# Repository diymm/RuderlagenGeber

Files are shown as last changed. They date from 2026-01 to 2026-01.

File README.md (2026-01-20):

## RuderlagenGeber NMEA 2000
Sensor im Eigenbau mit N2K Schnittstelle.
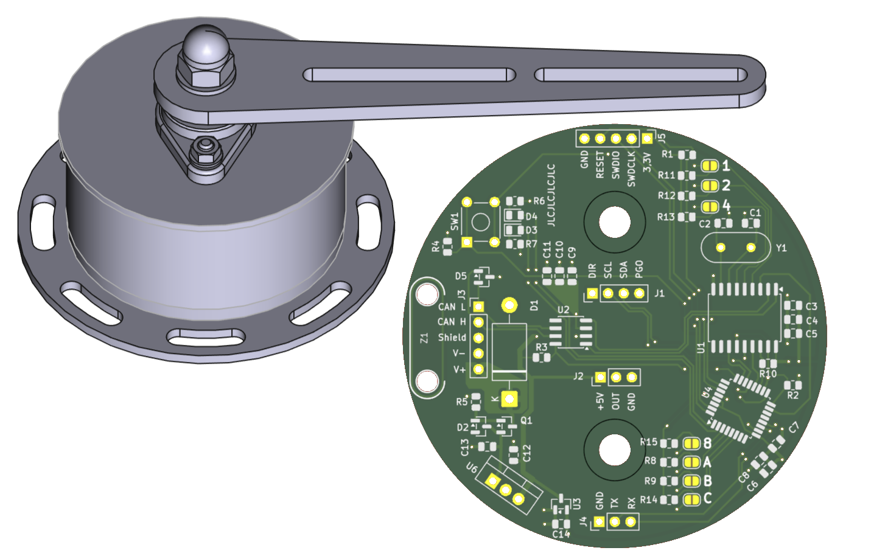
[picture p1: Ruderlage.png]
Ruderlagengeber


### Mechanischer Aufbau
Durch die Verwendung von Aluminium Blechteilen und Normteilen wird 
ein preisgünstigen Aufbau ermöglicht.\
Die Positionserfassung erfolgt magnetisch verschleissfrei und wird über 360°,\
ohne Anschlag erfasst. Eine mechanische Ausrichtung des Gebers ist nicht notwendig.
Über einen Taster wird die 0° Grad Position festgelegt und\
es kann eine Drehrichtungsumkehr eingeschaltet werden.

### Elektronik
Die Schaltung ist gegen Verpolung und Spannungspitzen geschützt\
und besteht im wesentlichen aus drei Komponenten:\
Dem Positionssensor AS5600\
einem CAN BUS Controller MCP2515\
und dem Kontroller SAMD21G17.\
Die Spannungsregelung wird energiesparend über einen Schaltregler geregelt. 
 
### Firmware
Die Firmware ist aktuell noch in der Testphase und wird noch ergänzt.
Im Testmode werden über die RS232 TTL verschiedene Zustände und Messwerte angezeigt,
auch ohne Ausgabe der Werte ist es mit Hilfe der LED möglich den Abstand des Magnetsensors
ausreichend genau einzustellen. 

### Vorstellung des Projekts auf YouTube
Eine Video Unterstützung auf YouTube steht zur weiteren Unterstützung bereit.
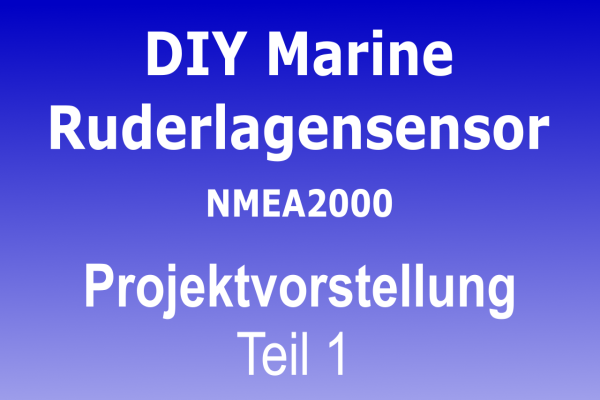
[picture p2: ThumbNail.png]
RuderlageThumbnail (https://www.youtube.com/watch?v=PicgXwzTuoU&t)


### Dokumentation
Durch die Verendung von KiCad für den Schaltplan und FreeCAD für die Zeichnungen ist eine Anpassung
an eigene Vorstellungen möglich.

### Lizenz
Alle Zeichnungen und der Programmcode können frei, nicht kommerziell, verwendet werden.\
creative commons (CC BY-NC 4.0) https://creativecommons.org/licenses/

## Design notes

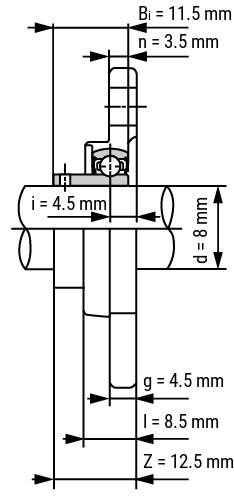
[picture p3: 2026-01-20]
Zeichnungen/silber-serie-miniatur-flanschlager-kfl08-welle-8-mm~3.jpg

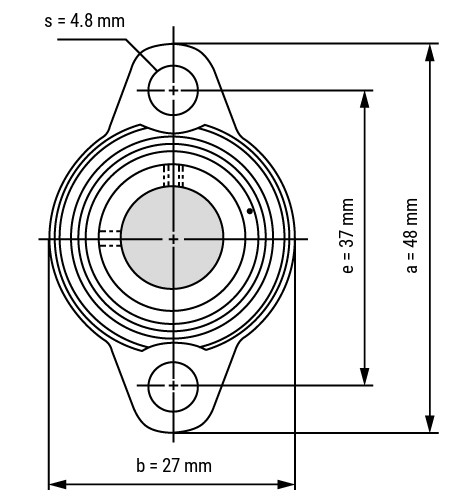
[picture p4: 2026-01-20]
Zeichnungen/silber-serie-miniatur-flanschlager-kfl08-welle-8-mm~2.jpg

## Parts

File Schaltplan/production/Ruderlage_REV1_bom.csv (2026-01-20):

Designator | Footprint | Quantity | Value | LCSC Part #
C1, C2 | 0805 | 2 | 22pF | C123150
C10, C4, C7 | 0805 | 3 | 1uF | C141772
C11, C3, C8 | 0805 | 3 | 100pF | C9900195991
C12, C13, C14, C5, C6, C9 | 0805 | 6 | 10uF | C356840
D1 | D_DO-201AE_P15.24mm_Horizontal | 1 | 1.5KExxA
D2 | SOT-23 | 1 | BZX 84-C4V7 | C143853
D3 | 0805 | 1 | LED gn | C2297
D4 | 0805 | 1 | LED rt | C84256
D5 | SOT-23 | 1 | PESD1CAN
Q1 | SOT-23 | 1 | NX2301P | C551594
R1 | 0805 | 1 | 1k | C9900143942
R10, R11, R14, R15, R2, R8, R9 | 0805 | 7 | 10k | C9900234692
R12, R13, R3, R4, R5 | 0805 | 5 | 10k
R6, R7 | 0805 | 2 | 200 | C2889551
SW1 | SW_TH_Tactile_Omron_B3F-10xx | 1 | SW_Omron_B3FS
U1 | SOIC-18W_7.5x11.6mm_P1.27mm | 1 | MCP2515-xSO
U2 | SOIC-8_3.9x4.9mm_P1.27mm | 1 | TJA1051T
U3 | SOT-23 | 1 | MCP1700x-120xxTT
U4 | TQFP-32_7x7mm_P0.8mm | 1 | ATSAMD21E17A-A | C618766
Z1 | Zugentlastung | 1 | ~

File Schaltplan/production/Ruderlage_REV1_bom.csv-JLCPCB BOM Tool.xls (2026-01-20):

JLCPCB BOM Tool - BOM Matching
BOM name：Ruderlage_REV1_bom-JLCPCB Assembly Order.xlsx |  |  |  | Download Time：2025-11-30 02:08:21 |  |  |  | * Our matching results are updated in real-time, but stock and prices may change. If it's been over 24 hours, please re-match before placing your order.
PCB Assembled Qty：5 |  |  |  | Est. Total Price：33.3095 (Pre-order parts require a quotation for final pricing.)
Your BOM |  |  |  | Matched Parts |  |  |  |  |  |  | Order Information
Designator | Comment | Footprint | JLCPCB Part # | Matches | Part # | Manufacturer | Footprint | Description | Category | Warning | JLCPCB Part # | Product link | Source | Lib Type | MOQ | Availability | My Parts(JLCPCB Parts) | My Parts(Global sourcing & consigned parts) | Rec. Order Qty | Unit Price ($) | Total Price ($)
U1 | MCP2515-xSO | SOIC-18W_7.5x11.6mm_P1.27mm |  | Select by System | MCP2515T-I/SO | Microchip Tech | SOIC-18W_7.5x11.6mm_P1.27mm | -40℃~+85℃ 1Mbps 1uA 2.7V~5.5V 5mA CAN Controller SPI SOIC-18-300mil CAN Controllers ROHS | CAN Controllers |  | C153782 | https://jlcpcb.com/partdetail/MicrochipTech-MCP2515T_ISO/C153782 | In-stock | Extended | 1 | 610 | 0 | 0 | 5 | 1.2885 | 6.4425
Q1 | NX2301P | SOT-23 |  | Select by Customer | NX2301P,215 | Nexperia | SOT-23 | -55℃~+150℃ 1 P-Channel 1.1V@250uA 115pF 120mΩ@4.5V 20V 2A 380pF 400mW 6nC@4.5V P-Channel SOT-23 MOSFETs ROHS | MOSFETs |  | C191273 | https://jlcpcb.com/partdetail/Nexperia-NX2301P215/C191273 | In-stock | Extended | 1 | 62 | 0 | 0 | 9 | 0.1847 | 1.6623
D2 | BZX 84-C4V7 | SOT-23 |  | Select by System | BZB784-C4V7,115 | Nexperia | SOT-23 | 1 Pair Common Anode 350mW 3uA@2V 4.4V~5V 4.7V 80Ω SOT-323(SC-70) Zener Diodes ROHS | Zener Diodes |  | C503444 | https://jlcpcb.com/partdetail/Nexperia-BZB784_C4V7115/C503444 | In-stock | Extended | 1 | 1321 | 0 | 0 | 9 | 0.1193 | 1.0737
C11,C3,C8 | 100pF | 0805 |  | Select by System | CC0805JRNPO9BN101 | YAGEO | 0805 | 100pF 50V NP0 ±5% 0805 Multilayer Ceramic Capacitors MLCC - SMD/SMT ROHS | Multilayer Ceramic Capacitors MLCC - SMD/SMT |  | C62768 | https://jlcpcb.com/partdetail/YAGEO-CC0805JRNPO9BN101/C62768 | In-stock | Extended | 1 | 33006 | 0 | 0 | 25 | 0.0053 | 0.1325
R10,R11,R14,R15,R2,R8,R9 | 10k | 0805 |  | Select by System | 0805W8F1002T5E | UNI-ROYAL(Uniroyal Elec) | 0805 | -55℃~+155℃ 10kΩ 125mW 150V Thick Film Resistor ±1% ±100ppm/℃ 0805 Chip Resistor - Surface Mount ROHS | Chip Resistor - Surface Mount |  | C17414 | https://jlcpcb.com/partdetail/18102-0805W8F1002T5E/C17414 | In-stock | Basic | 1 | 12077584 | 0 | 0 | 70 | 0.0018 | 0.126
R12,R13,R3,R4,R5 | 10k | 0805 |  | Unconfirmed | 0805W8F1002T5E | UNI-ROYAL(Uniroyal Elec) | 0805 | -55℃~+155℃ 10kΩ 125mW 150V Thick Film Resistor ±1% ±100ppm/℃ 0805 Chip Resistor - Surface Mount ROHS | Chip Resistor - Surface Mount | 1.The comment (0805W8F1002T5E) of this part does not match the one (10k) provided in your BOM. Please confirm; | C17414 | https://jlcpcb.com/partdetail/18102-0805W8F1002T5E/C17414 | In-stock | Basic | 1 | 12077584 | 0 | 0 | 70 | 0.0018 | 0.126
R1 | 1k | 0805 |  | Select by System | 0805W8F1001T5E | UNI-ROYAL(Uniroyal Elec) | 0805 | -55℃~+155℃ 125mW 150V 1kΩ Thick Film Resistor ±1% ±100ppm/℃ 0805 Chip Resistor - Surface Mount ROHS | Chip Resistor - Surface Mount |  | C17513 | https://jlcpcb.com/partdetail/18201-0805W8F1001T5E/C17513 | In-stock | Basic | 1 | 15084219 | 0 | 0 | 20 | 0.0017 | 0.034
U4 | ATSAMD21E17A-A | TQFP-32_7x7mm_P0.8mm |  | Select by System | ATSAMD21E17A-AU | Microchip Tech | TQFP-32_7x7mm_P0.8mm | 1.62V~3.6V 10bit 128KB 12bit 26 48MHz ARM Cortex-M Series FLASH TQFP-32(7x7) Microcontrollers (MCU/MPU/SOC) ROHS | Microcontrollers (MCU/MPU/SOC) |  | C1337408 | https://jlcpcb.com/partdetail/MicrochipTech-ATSAMD21E17AAU/C1337408 | In-stock | Extended | 1 | 20 | 0 | 0 | 5 | 3.813 | 19.065
C10,C4,C7 | 1uF | 0805 |  | Select by System | CL21B105KOFNNNE | Samsung Electro-Mechanics | 0805 | 16V 1uF X7R ±10% 0805 Multilayer Ceramic Capacitors MLCC - SMD/SMT ROHS | Multilayer Ceramic Capacitors MLCC - SMD/SMT |  | C24123 | https://jlcpcb.com/partdetail/24863-CL21B105KOFNNNE/C24123 | In-stock | Extended | 1 | 331792 | 0 | 0 | 25 | 0.0097 | 0.2425
C12,C13,C14,C5,C6,C9 | 10uF | 0805 |  | Select by System | CL21A106KPFNNNE | Samsung Electro-Mechanics | 0805 | 10V 10uF X5R ±10% 0805 Multilayer Ceramic Capacitors MLCC - SMD/SMT ROHS | Multilayer Ceramic Capacitors MLCC - SMD/SMT |  | C17024 | https://jlcpcb.com/partdetail/17708-CL21A106KPFNNNE/C17024 | In-stock | Extended | 1 | 1625820 | 0 | 0 | 40 | 0.0091 | 0.364
D5 | PESD1CAN | SOT-23 |  | Select by System | PESD1CAN | BORN | SOT-23 | 12pF 24V 26.7V 280W@8/20us 48V 500nA 6A Bidirectional ESD IEC 61000-4-2 SOT-23 ESD and Surge Protection (TVS/ESD) ROHS | ESD and Surge Protection (TVS/ESD) |  | C343993 | https://jlcpcb.com/partdetail/BORN-PESD1CAN/C343993 | In-stock | Extended | 1 | 64359 | 0 | 0 | 9 | 0.075 | 0.675
R6,R7 | 200 | 0805 |  | Select by System | 0805W8F2000T5E | UNI-ROYAL(Uniroyal Elec) | 0805 | -55℃~+155℃ 125mW 150V 200Ω Thick Film Resistor ±1% ±100ppm/℃ 0805 Chip Resistor - Surface Mount ROHS | Chip Resistor - Surface Mount |  | C17540 | https://jlcpcb.com/partdetail/18228-0805W8F2000T5E/C17540 | In-stock | Basic | 1 | 1684208 | 0 | 0 | 20 | 0.0018 | 0.036
C1,C2 | 22pF | 0805 |  | Select by System | CL21C220JBANNNC | Samsung Electro-Mechanics | 0805 | 22pF 50V C0G ±5% 0805 Multilayer Ceramic Capacitors MLCC - SMD/SMT ROHS | Multilayer Ceramic Capacitors MLCC - SMD/SMT |  | C1804 | https://jlcpcb.com/partdetail/2156-CL21C220JBANNNC/C1804 | In-stock | Basic | 1 | 405912 | 0 | 0 | 20 | 0.0091 | 0.182
D4 | LED rt | 0805 |  | Select by System | NCD0805R1 | Foshan NationStar Optoelectronics | 0805 | -30℃~+85℃ 1.6V~2.6V 130° 195mcd 25mA 615nm~630nm 630nm 65mW Discrete Diode Red 0805 LED Indication - Discrete ROHS | LED Indication - Discrete |  | C84256 | https://jlcpcb.com/partdetail/85425-NCD0805R1/C84256 | In-stock | Basic | 1 | 6231906 | 0 | 0 | 20 | 0.0116 | 0.232
D3 | LED gn | 0805 |  | Select by System | KT-0805G | Hubei KENTO Elec | 0805 | -40℃~+85℃ 100mW 120° 2.6V~3.1V 430mcd 513nm~528nm 525nm 5mA Emerald Green 0805 LED Indication - Discrete ROHS | LED Indication - Discrete |  | C2297 | https://jlcpcb.com/partdetail/Hubei_KENTOElec-KT0805G/C2297 | In-stock | Basic | 1 | 2581235 | 0 | 0 | 20 | 0.0108 | 0.216
U2 | TJA1051T | SOIC-8_3.9x4.9mm_P1.27mm |  | Select by System | TJA1051T | Tokmas | SOIC-8_3.9x4.9mm_P1.27mm | -40℃~+150℃ 4.5V~5.5V 5Mbps 70mA CAN FD Transceiver SOP-8 CAN Transceivers ROHS | CAN Transceivers |  | C7432801 | https://jlcpcb.com/partdetail/Tokmas-TJA1051T/C7432801 | In-stock | Extended | 1 | 1532 | 0 | 0 | 5 | 0.54 | 2.7
Z1 | ~ | Zugentlastung |  | No matches |  | No Part Selected
D1 | 1.5KExxA | D_DO-201AE_P15.24mm_Horizontal |  | No matches |  | No Part Selected
SW1 | SW_Omron_B3FS | SW_TH_Tactile_Omron_B3F-10xx |  | No matches |  | No Part Selected
U3 | MCP1700x-120xxTT | SOT-23 |  | No matches |  | No Part Selected

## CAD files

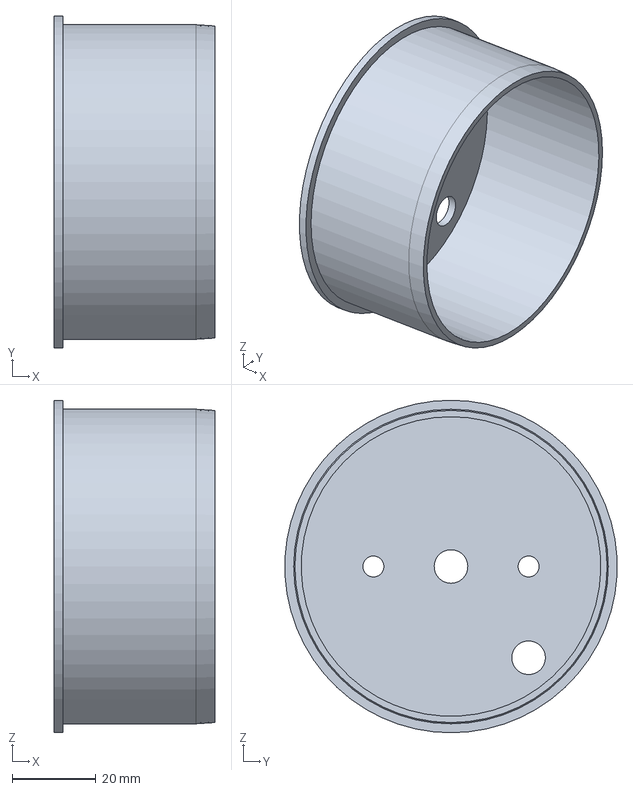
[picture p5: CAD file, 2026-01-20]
Zeichnungen/HtMuffenstopfenDn75.FCStd
38.3 x 79.1 x 79.3 mm

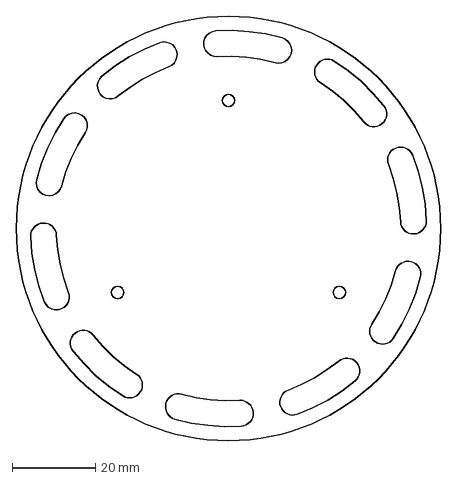
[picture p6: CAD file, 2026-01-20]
Zeichnungen/Ruderlage_Bodenplatte.dxf
102.0 x 102.0 mm

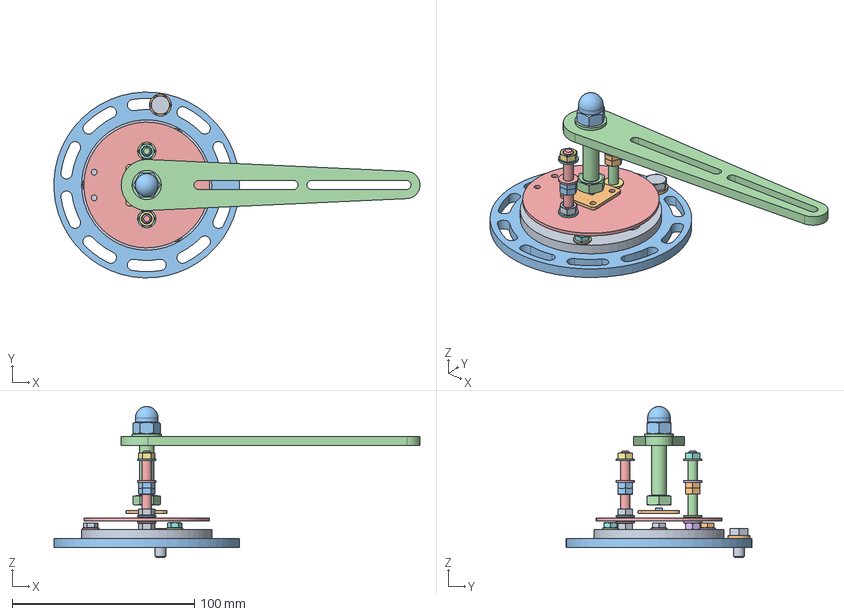
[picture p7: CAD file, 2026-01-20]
Zeichnungen/RuderlageV2.FCStd
200.9 x 102.0 x 82.9 mm
Montageplatte
Platine
Soic8
M5x48-ThreadedRod
M5x48-ThreadedRod001
M5-Nut
M5-Nut007
M5-Nut008
M5-Nut016
M5-Nut009
M5-Nut010
M5-Washer001
M5-Washer003
M5-Washer002
M5-Washer004
M5-Washer005
M6x12-Screw
M6-Washer
M8-Nut
M5-Washer
M5-Washer016
M5-Washer014
M5-Washer015
M5-Nut017
M5-Nut011
M5-Nut012
M8-Washer
M4-Washer
M4-Washer003
M4-Washer004
M4x10-Screw0
M4x10-Screw
M4x10-Screw001
Montageplatte1
Arm001
MotherBoard

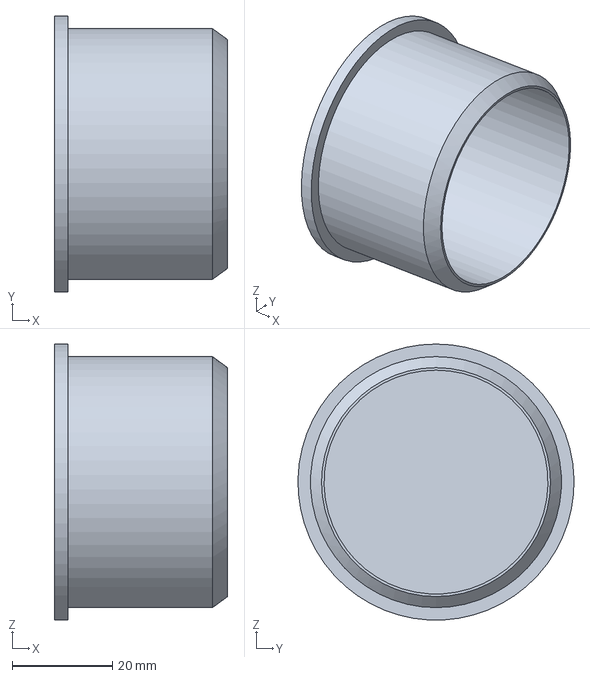
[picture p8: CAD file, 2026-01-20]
Zeichnungen/HtMuffenstopfenDn50.FCStd
34.5 x 55.0 x 55.0 mm

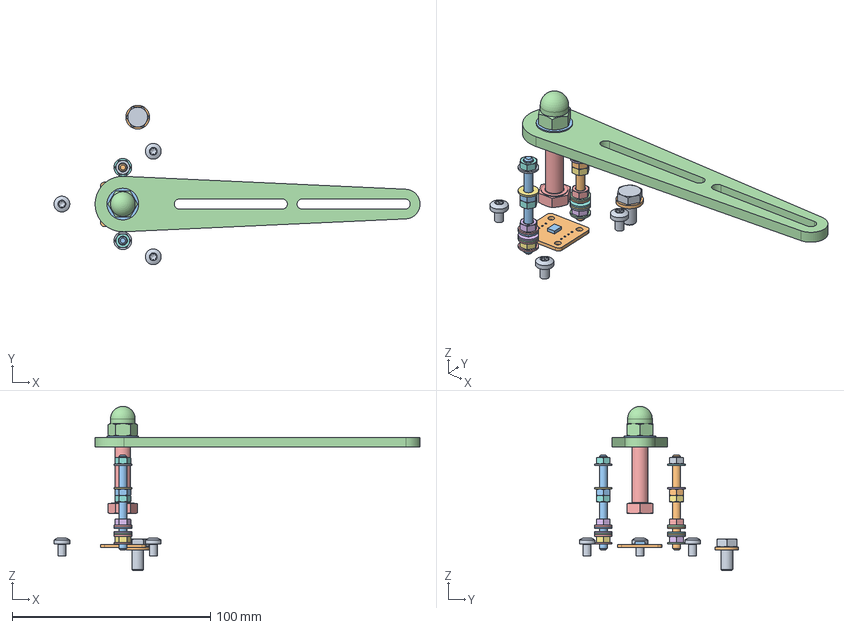
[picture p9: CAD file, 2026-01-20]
Zeichnungen/Ruderlage.FCStd
184.7 x 80.5 x 82.9 mm
Platine
Soic8
Arm001
M4-Nut
M4-Nut016
M4-Nut018
M4-Nut017
M4-Nut022
M4-Nut021
M8-Nut
M4-Nut025
M4-Nut024
M4-Nut028
M4-Nut029
M6x12-Screw
M4x48-ThreadedRod
M4x48-ThreadedRod001
M4-Washer
M4-Washer014
M4-Washer020
M4-Washer019
M4-Washer015
M4-Washer016
M6-Washer
M8-Washer
M4-Washer025
M4-Washer026
M4-Washer027
M4-Washer051
M4-Washer052
M4-Washer053
M4-Washer056
M4-Washer054
M4-Washer057
M4-Washer055

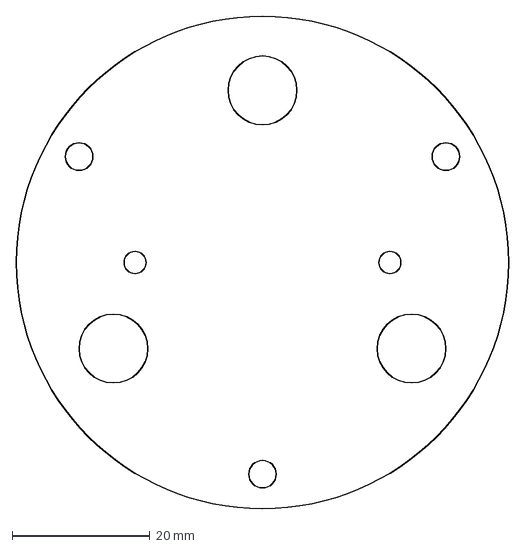
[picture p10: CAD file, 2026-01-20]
Zeichnungen/Ruderlage_Innenplatte.dxf
71.5 x 71.5 mm

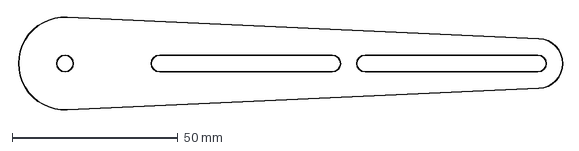
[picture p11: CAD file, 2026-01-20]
Zeichnungen/Ruderlage_Arm.dxf
164.7 x 28.4 mm

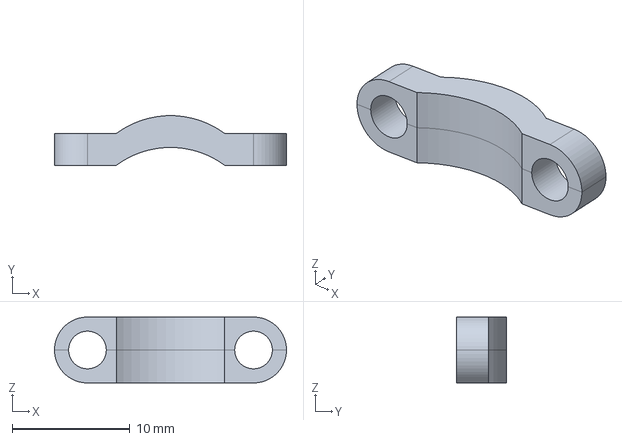
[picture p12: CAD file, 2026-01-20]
Zeichnungen/ZugentlastungKAZU_0442.FCStd
19.7 x 4.21 x 5.60 mm

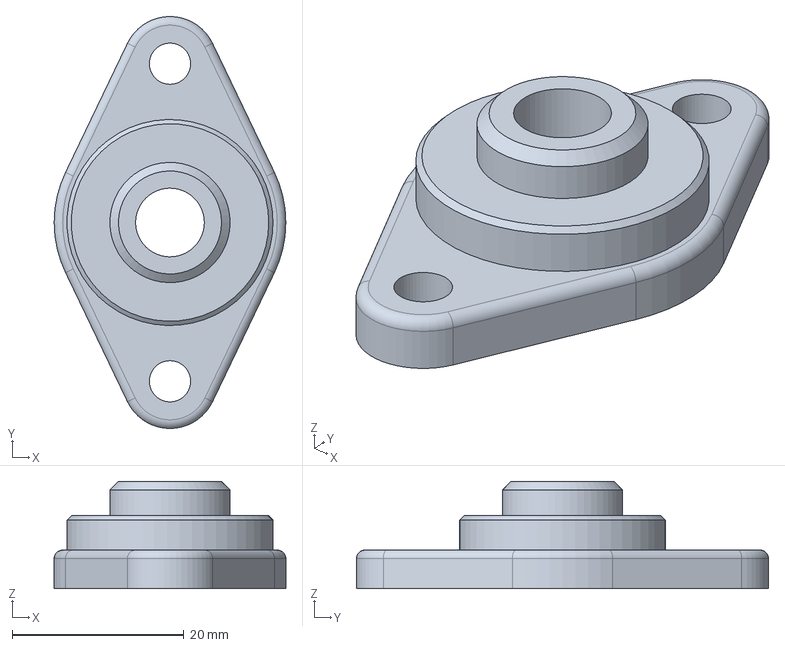
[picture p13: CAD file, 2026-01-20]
Zeichnungen/KFL08.FCStd
27.0 x 48.0 x 12.5 mm

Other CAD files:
Zeichnungen/Assembly.FCStd
Zeichnungen/WinkelTestZeichnung.FCStd

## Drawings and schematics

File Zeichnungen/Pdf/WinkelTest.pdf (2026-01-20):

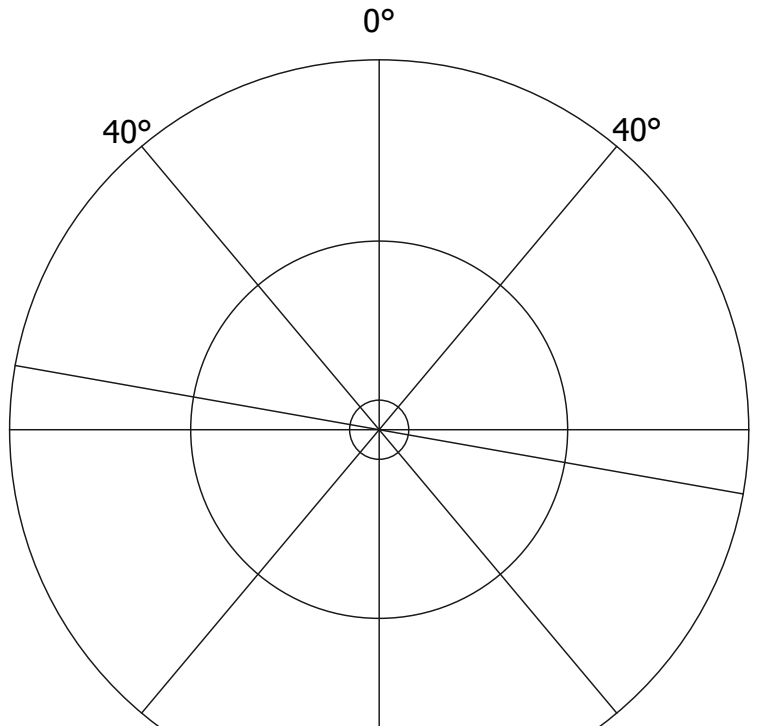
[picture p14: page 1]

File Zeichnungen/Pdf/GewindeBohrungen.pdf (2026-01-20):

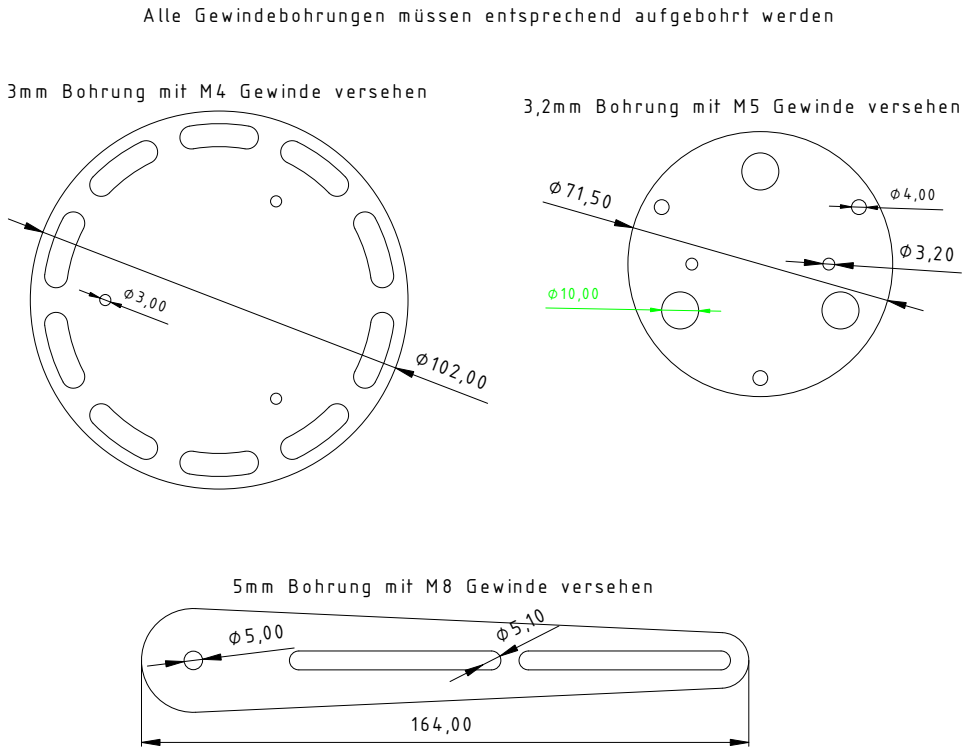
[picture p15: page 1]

A lle G e w indebohrungen m üssen entsprechend aufgebohrt w erden

3m m B ohrung m it M 4 G e w inde versehen

3,2m m B ohrung m it M 5 G e w inde versehen

5m m B ohrung m it M 8 G e w inde versehen

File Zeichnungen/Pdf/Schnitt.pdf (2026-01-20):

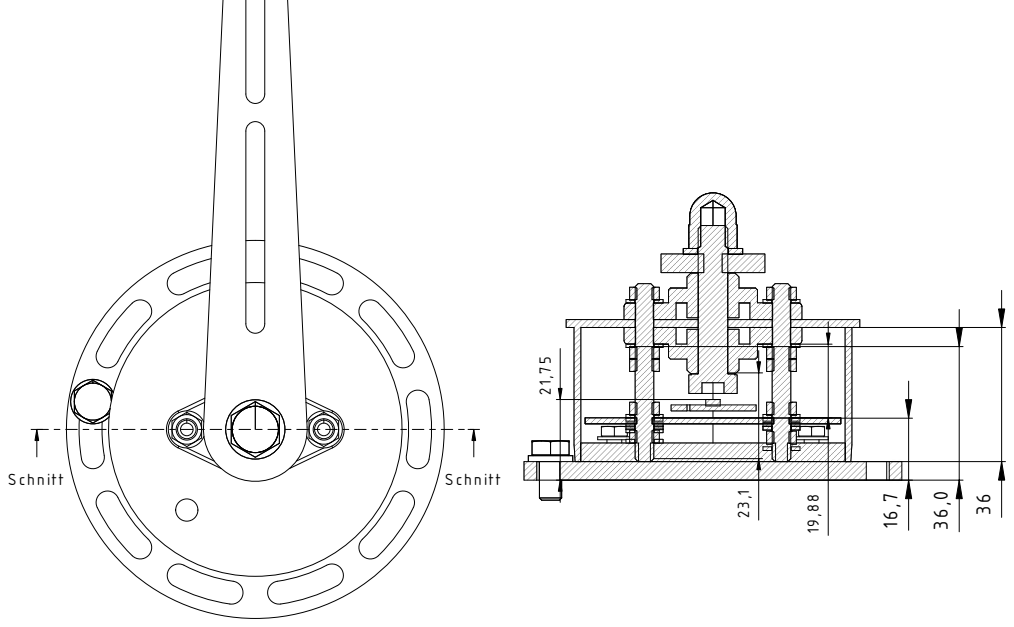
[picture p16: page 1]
S chnitt

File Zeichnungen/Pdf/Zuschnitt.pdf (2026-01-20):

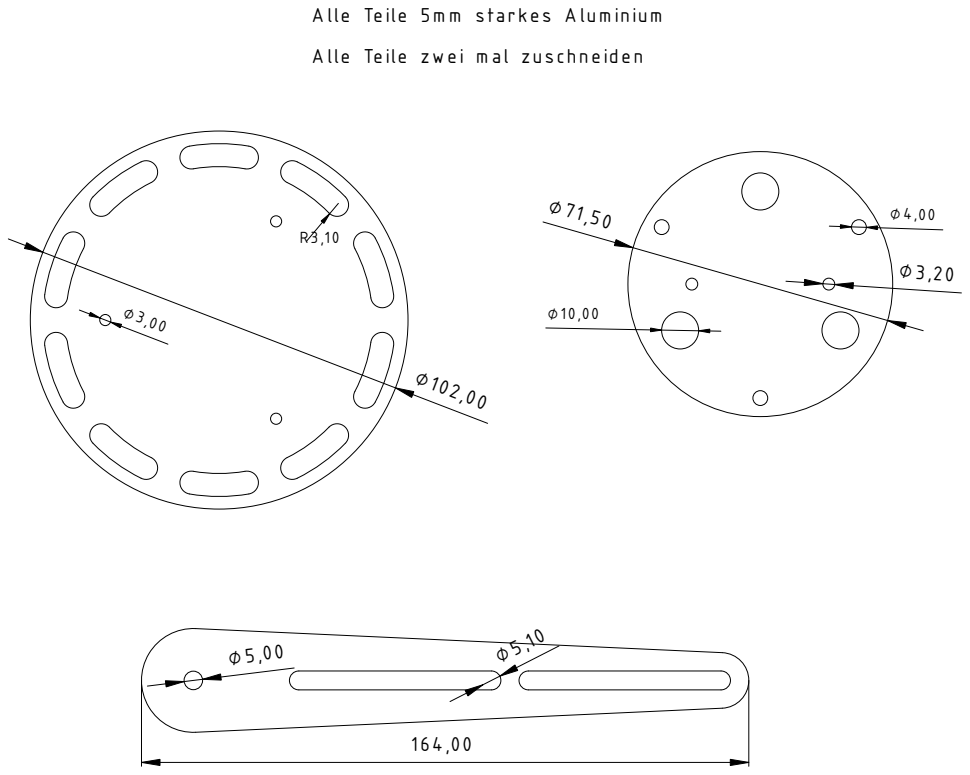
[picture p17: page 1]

A lle Teile 5m m starkes A lum inium
A lle Teile zw ei m al zuschneiden

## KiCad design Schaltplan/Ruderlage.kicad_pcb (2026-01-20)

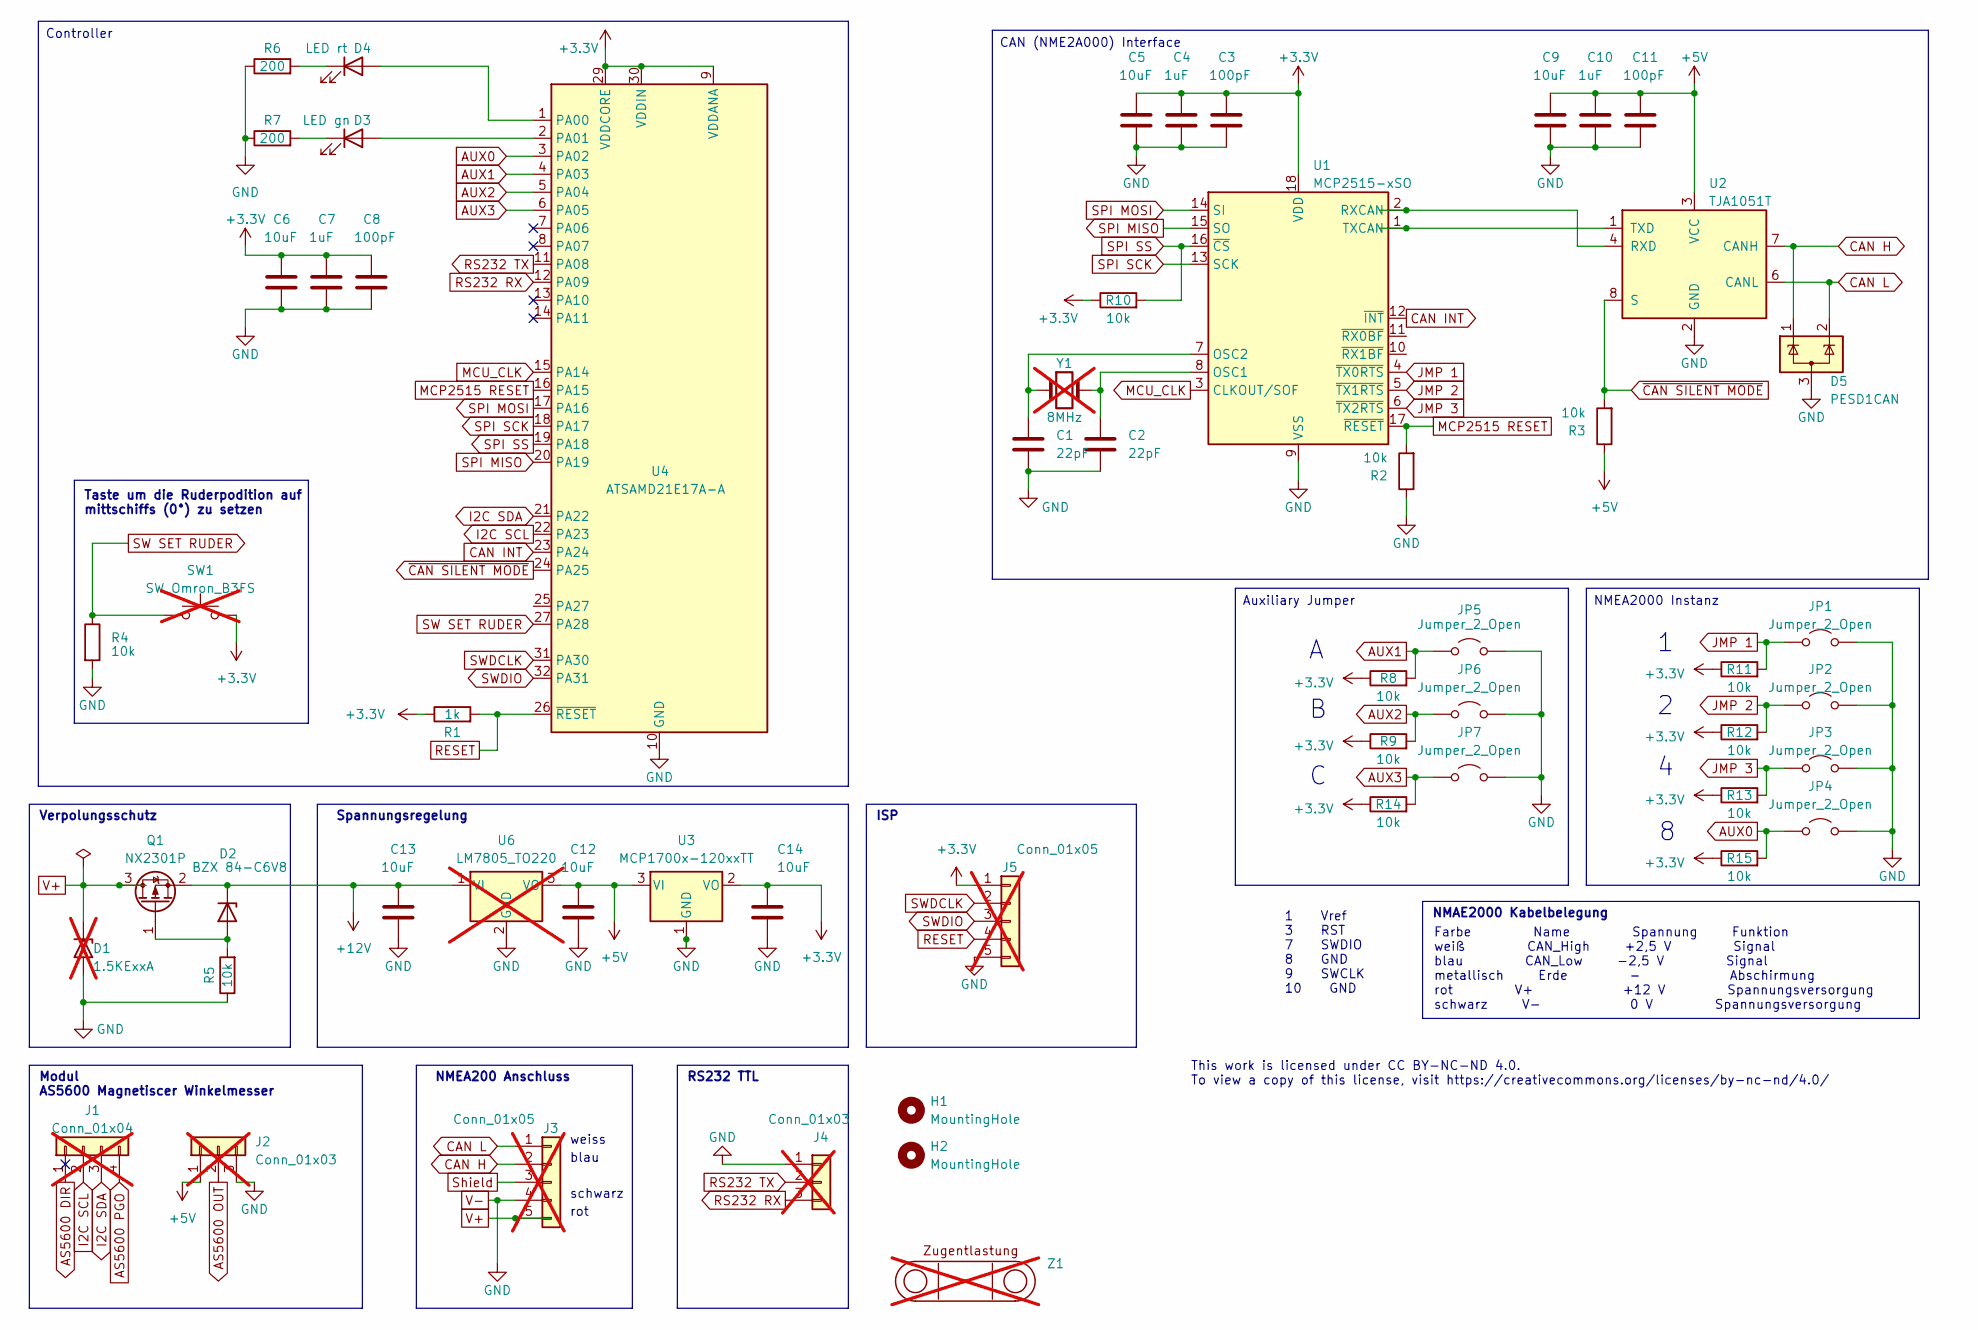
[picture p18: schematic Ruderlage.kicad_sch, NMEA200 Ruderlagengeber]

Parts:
C1, C2: 22pF; C_0805_2012Metric
C3, C8, C11: 100pF; C_0805_2012Metric; LCSC C9900195991
C4, C7, C10: 1uF; C_0805_2012Metric
C5, C6, C9, C12, C13, C14: 10uF; C_0805_2012Metric
D1: 1.5KExxA; D_DO-201AE_P15.24mm_Horizontal; not fitted
D2: BZX 84-C6V8; SOT-23
D3: LED gn; LED_0805_2012Metric
D4: LED rt; LED_0805_2012Metric
D5: PESD1CAN; SOT-23
H1, H2: MountingHole; MountingHole_5mm
J1: Conn_01x04; PinHeader_1x04_P2.54mm_Vertical; not fitted
J2, J4: Conn_01x03; PinHeader_1x03_P2.54mm_Vertical; not fitted
J3, J5: Conn_01x05; PinHeader_1x05_P2.54mm_Vertical; not fitted
JP1, JP2, JP3, JP4, JP5, JP6, JP7: Jumper_2_Open; SolderJumper-2_P1.3mm_Open_RoundedPad1.0x1.5mm
Q1: NX2301P; SOT-23; LCSC C551594
R1: 1k; R_0805_2012Metric; LCSC C9900143942
R2, R8, R9, R10, R11, R14, R15: 10k; R_0805_2012Metric; LCSC C9900234692
R3, R4, R5, R12, R13: 10k; R_0805_2012Metric
R6, R7: 200; R_0805_2012Metric; LCSC C2889551
SW1: SW_Omron_B3FS; SW_TH_Tactile_Omron_B3F-10xx; not fitted
U1: MCP2515-xSO; SOIC-18W_7.5x11.6mm_P1.27mm
U2: TJA1051T; SOIC-8_3.9x4.9mm_P1.27mm
U3: MCP1700x-120xxTT; SOT-23
U4: ATSAMD21E17A-A; TQFP-32_7x7mm_P0.8mm; LCSC C618766
U6: LM7805_TO220; TO-220-3_Vertical; not fitted
Y1: 8MHz; Crystal_HC49-4H_Vertical; not fitted
Z1: Zugentlastung; not fitted

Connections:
+3.3V: C3.1, C4.1, C5.1, C6.1, C7.1, C8.1, C14.1, J5.1, R1.1, R8.1, R9.1, R10.1, R11.1, R12.1, R13.1, R14.1, R15.1, SW1.2, U1.18 (VDD), U3.2 (VO), U4.9 (VDDANA), U4.29 (VDDCORE), U4.30 (VDDIN)
+5V: C9.1, C10.1, C11.1, C12.1, J2.1, R3.1, U2.3 (VCC), U3.3 (VI), U6.3 (VO)
+12V: C13.1, D2.3 (K), Q1.2 (S), U6.1 (VI)
AS5600 DIR: J1.1
AS5600 OUT: J2.2
AS5600 PGO: J1.4
AUX0: JP4.1 (A), R15.2, U4.3 (PA02)
AUX1: JP5.1 (A), R8.2, U4.4 (PA03)
AUX2: JP6.1 (A), R9.2, U4.5 (PA04)
AUX3: JP7.1 (A), R14.2, U4.6 (PA05)
CAN H: D5.1 (K), J3.2, U2.7 (CANH)
CAN INT: U1.12 (~INT), U4.23 (PA24)
CAN L: D5.2 (K), J3.1, U2.6 (CANL)
I2C SCL: J1.2, U4.22 (PA23)
I2C SDA: J1.3, U4.21 (PA22)
JMP 1: JP1.1 (A), R11.2, U1.4 (~TX0RTS)
JMP 2: JP2.1 (A), R12.2, U1.5 (~TX1RTS)
JMP 3: JP3.1 (A), R13.2, U1.6 (~TX2RTS)
MCP2515 RESET: R2.2, U1.17 (~RESET), U4.16 (PA15)
MCU_CLK: U1.3 (CLKOUT/SOF), U4.15 (PA14)
unnamed: D2.1 (A), Q1.1 (G), R5.2
unnamed: D3.2 (A), U4.2 (PA01)
unnamed: D3.1 (K), R7.2
unnamed: D4.2 (A), U4.1 (PA00)
unnamed: D4.1 (K), R6.2
unnamed: C2.1, U1.8 (OSC1), Y1.2
unnamed: C1.1, U1.7 (OSC2), Y1.1
unnamed: U1.2 (RXCAN), U2.4 (RXD)
unnamed: U1.1 (TXCAN), U2.1 (TXD)
RESET: J5.4, R1.2, U4.26 (~RESET)
RS232 RX: J4.3, U4.12 (PA09)
RS232 TX: J4.2, U4.11 (PA08)
SPI MISO: U1.15 (SO), U4.20 (PA19)
SPI MOSI: U1.14 (SI), U4.17 (PA16)
SPI SCK: U1.13 (SCK), U4.18 (PA17)
SPI SS: R10.2, U1.16 (~CS), U4.19 (PA18)
SW SET RUDER: R4.1, SW1.1, U4.27 (PA28)
SWDCLK: J5.2, U4.31 (PA30)
SWDIO: J5.3, U4.32 (PA31)
Shield: J3.3
V+: D1.1 (A1), J3.5, Q1.3 (D)
V-: C1.2, C2.2, C3.2, C4.2, C5.2, C6.2, C7.2, C8.2, C9.2, C10.2, C11.2, C12.2, C13.2, C14.2, D1.2 (A2), D5.3 (A), J2.3, J3.4, J4.1, J5.5, JP1.2 (B), JP2.2 (B), JP3.2 (B), JP4.2 (B), JP5.2 (B), JP6.2 (B), JP7.2 (B), R2.1, R4.2, R5.1, R6.1, R7.1, U1.9 (VSS), U2.2 (GND), U3.1 (GND), U4.10 (GND), U4.28 (GND), U6.2 (GND)
~CAN SILENT MODE: R3.2, U2.8 (S), U4.24 (PA25)

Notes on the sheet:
weiss
rot
1 Vref 3 RST 7 SWDIO 8 GND 9 SWCLK 10 GND
Taste um die Ruderpodition auf mittschiffs (0°) zu setzen
Spannungsregelung
This work is licensed under CC BY-NC-ND 4.0. To view a copy of this license, visit https://creativecommons.org/licenses/by-nc-nd/4.0/
ISP
NMAE2000 Kabelbelegung
NMEA200 Anschluss
schwarz
blau
Farbe Name Spannung Funktion weiß CAN_High +2,5 V Signal blau CAN_Low −2,5 V Signal metallisch Erde - Abschirmung rot V+ +12 V Spannungsversorgung schwarz V− 0 V Spannungsversorgung
RS232 TTL
Modul AS5600 Magnetiscer Winkelmesser
Verpolungsschutz
Controller
NMEA2000 Instanz
Auxiliary Jumper
CAN (NME2A000) Interface

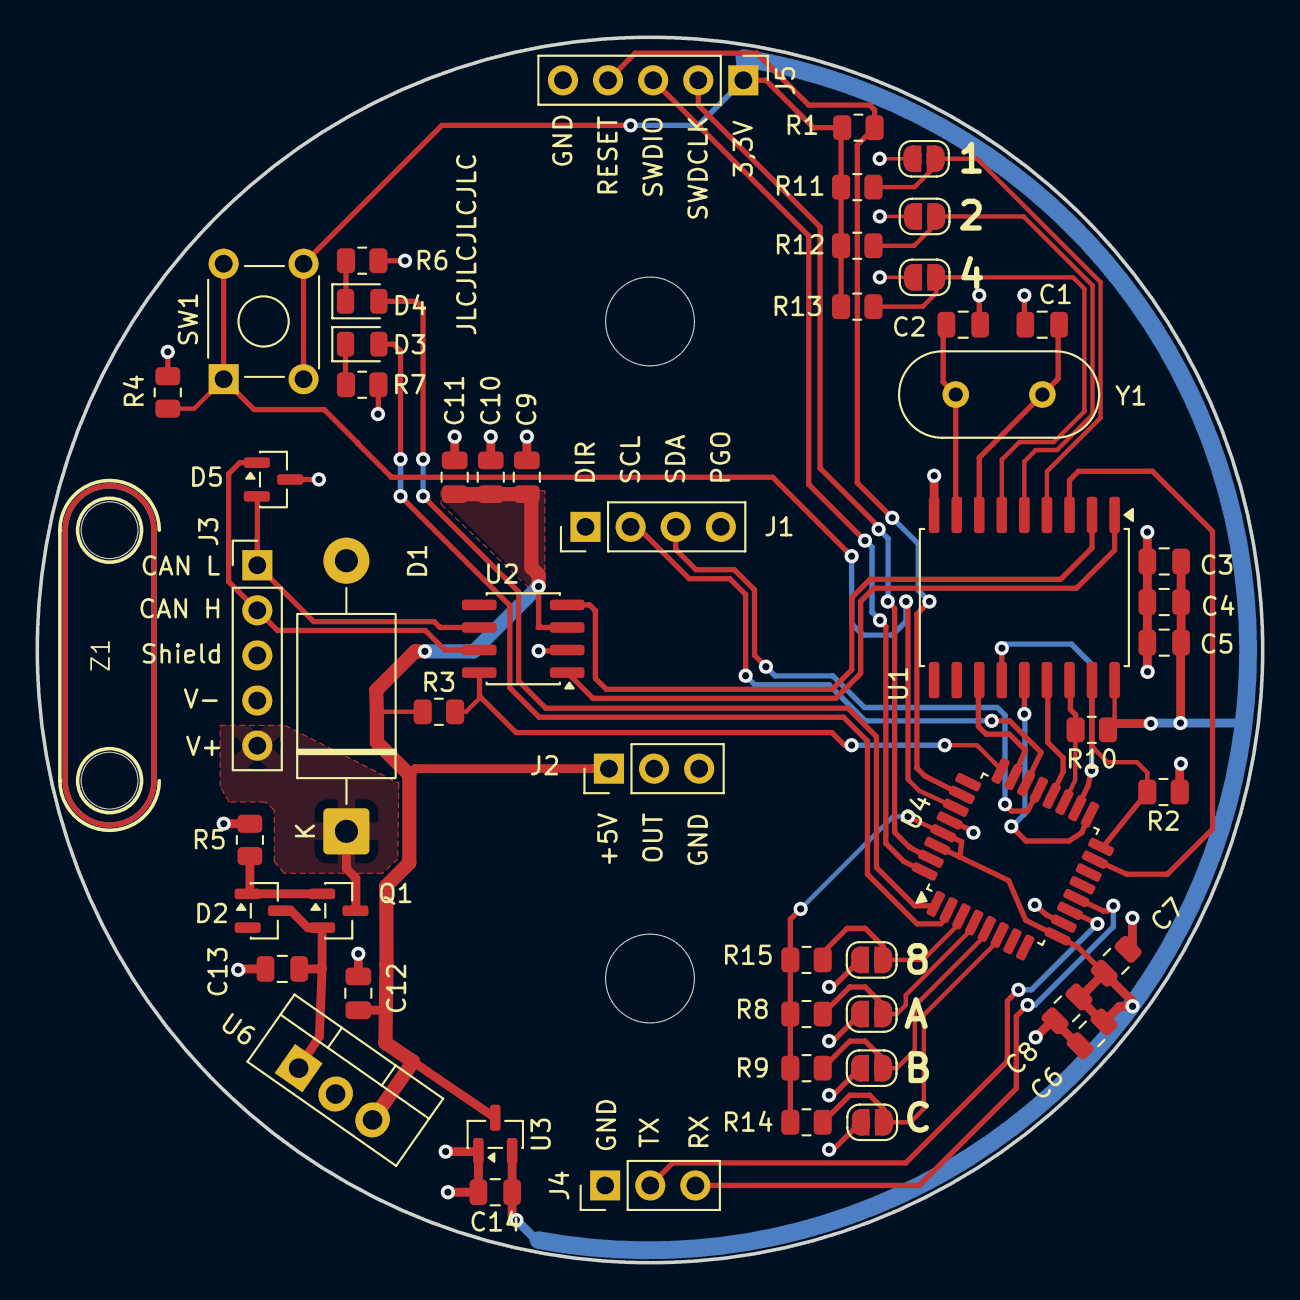
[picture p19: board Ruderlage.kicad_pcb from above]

Board: 2 copper layers, 69.0 x 69.0 mm, 57 parts (0 on the bottom side), 39 nets.
